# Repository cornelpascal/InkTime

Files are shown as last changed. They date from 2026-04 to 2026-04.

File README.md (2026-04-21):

# InkTime

- Cerinta proiectului: https://ocw.cs.pub.ro/courses/tsc/proiect2026
- Portalul de piese JLC mentionat in brief: https://jlcpcb.com/parts

Repository-ul contine schema electrica, PCB-ul, fisierele de manufacturing si ansamblul mecanic pentru un wearable bazat pe nRF52840, cu Bluetooth Low Energy, incarcare prin USB-C, interfata pentru display e-paper, motion sensing, haptic feedback si monitorizare baterie.

## Continutul Repository-ului

- `Hardware/`
  - `WatchSchematic.sch` - schema nativa
  - `WatchSchematic.brd` - layout PCB nativ
  - `WatchSchematic.pdf` / `WatchSchematic1.pdf` - exporturi PDF ale schemei
- `Manufacturing/`
  - `Gerbers.zip` - exporturi Gerber, drill si assembly
  - `bom.csv` - export BOM pentru manufacturing
  - `pick_and_place_top.cpl` - date de plasare pentru fata top
  - `pick_and_place_bottom.cpl` - date de plasare pentru fata bottom
- `Mechanical/`
  - `WatchMechanical.f3z` - assembly Fusion 360
  - `WatchMechanical.step` - export CAD neutru
- `Images/`
  - capturi de render pentru PCB/dispozitiv

## Diagrama Bloc

```text
                         +----------------------+
USB-C -----------------> | USB ESD Protection   |
                         +----------+-----------+
                                    |
                                    v
                         +----------------------+
                         | BQ25180 Charger/PMIC |
                         +----+------------+----+
                              |            |
                              |            +--------------------+
                              v                                 |
                       +-------------+                          |
                       | Li-Po       |                          |
                       | Battery     | --------------------+   |
                       +------+------+                     |   |
                              |                            v   v
                              |                  +----------------------+
                              +----------------> | MAX17048 Fuel Gauge  |
                                                 +----------------------+

                         +----------------------+
                         | RT6160A Buck-Boost   |
                         | 3.3 V Regulator      |
                         +----+----+----+-------+
                              |    |    |
                              |    |    +---------------------> Display E-Paper pe FPC 24 pini
                              |    |
                              |    +-------------------------> DRV2605 Haptic Driver ---> Motor vibratii
                              |
                              +------------------------------> BMA423 IMU
                              |
                              v
                    +-----------------------------------+
                    | nRF52840 BLE + USB MCU            |
                    |                                   |
                    | I2C  -> PMIC / Fuel / IMU / Haptic|
                    | SPI  -> Display E-Paper           |
                    | GPIO -> Butoane / INT / EN        |
                    | USB  -> D+ / D-                   |
                    | SWD  -> Debug Tag-Connect         |
                    +-----+-----------+--------+--------+
                          |           |        |
                          |           |        +--------> Tag-Connect SWD
                          |           +-----------------> 3 butoane user
                          +-----------------------------> Matching Network -> Antena 2.4 GHz
```

## Prezentare Hardware

### Arhitectura principala

- `nRF52840` este controlerul principal. A fost ales deoarece combina BLE, USB, suficienti GPIO, moduri low-power si un ecosistem RF intr-un singur pachet.
- Alimentarea intra prin `USB-C`, trece prin protectia ESD si este gestionata de `BQ25180YBGR`, un charger / PMIC pentru o singura celula.
- Linia de alimentare sustinuta de baterie este reglata de `RT6160AWSC`, un convertor buck-boost care genereaza rail-ul principal `3V3` indiferent de variatia tensiunii bateriei.
- Starea bateriei este masurata de `MAX17048G+T10`.
- Motion sensing este oferit de `BMA423`.
- Haptic feedback este generat de `DRV2605YZFR`, controlat prin I2C si activat printr-un GPIO dedicat.
- Display-ul este conectat printr-un conector `FPC 24 pini, 0.5 mm` si foloseste o magistrala dedicata de tip SPI plus linii de reset/busy/control.
- Semnalul RF de la nRF52840 trece printr-o retea discreta de matching catre o antena chip de 2.4 GHz plasata pe marginea PCB-ului.

### Decizii de design vizibile in implementare

- Toate componentele populate sunt plasate pe fata top; fisierul pick-and-place pentru bottom este gol, conform ghidajului din cerinta.
- Antena RF este pastrata pe marginea placii si separata de zonele dense de cupru, ceea ce respecta cerinta proiectului privind clearance-ul antenei.
- Ceasul foloseste trei butoane hardware pe GPIO-uri dedicate in loc sa le multiplexeze prin display sau PMIC.

## Bill of Materials

BOM-ul complet exportat pentru manufacturing este in [`Manufacturing/bom.csv`](Manufacturing/bom.csv). Tabelul de mai jos listeaza componentele functionale principale, iar coloana `JLC Parts` foloseste fie linkul exact extras din proiect, fie portalul JLC Parts pentru cautarea manuala dupa MPN atunci cand codul JLC nu apare explicit in export.

| Ref | Part | Rol | JLC Parts | Datasheet |
| --- | --- | --- | --- | --- |
| `U1` | nRF52840 | MCU principal BLE/USB | https://jlcpcb.com/partdetail/JLCPCBAssembly-nRF52840/C9900031370 | https://www.nordicsemi.com/-/media/Software-and-other-downloads/Product-Briefs/nRF52840-product-brief.pdf |
| `IC1` | BQ25180YBGR | Charger / PMIC pentru o singura celula | https://jlcpcb.com/partdetail/TexasInstruments-BQ25180YBGR/C3682423 | https://www.ti.com/lit/ds/symlink/bq25180.pdf |
| `IC9` | RT6160AWSC | Regulator buck-boost 3.3 V | https://jlcpcb.com/partdetail/C7065276 | https://www.richtek.com/assets/product_file/RT6160A=RTQ2520A/DS6160A-05.pdf |
| `U3` | MAX17048G+T10 | Fuel gauge pentru baterie | https://jlcpcb.com/partdetail/MaximIntegrated-MAX17048GT10/C2682616 | https://www.analog.com/media/en/technical-documentation/data-sheets/MAX17048-MAX17049.pdf |
| `IC2` | DRV2605YZFR | Driver haptic | https://jlcpcb.com/partdetail/TexasInstruments-DRV2605YZFR/C81079 | https://www.ti.com/lit/ds/symlink/drv2605.pdf |
| `L7` | FTC252012SR47MBCA | Inductor pentru buck-boost | https://jlcpcb.com/partdetail/6763488-FTC252012SR47MBCA/C5832368 | https://product.tdk.com/system/files/dam/doc/product/inductor/inductor/smd/catalog/inductor_commercial_power_mlp2016_en.pdf |
| `IC3` | BMA423 | Accelerometru pe 3 axe | https://jlcpcb.com/parts | https://www.bosch-sensortec.com/media/boschsensortec/downloads/datasheets/bst-bma423-ds000.pdf |
| `ANT1` | 2450AT18B100E | Antena chip 2.4 GHz | https://jlcpcb.com/parts | https://www.johansontechnology.com/datasheets/2450AT18B100.pdf |
| `J1` | Molex 503480-2400 | Conector FPC 24 pini pentru display | https://jlcpcb.com/parts | https://www.molex.com/pdm_docs/sd/5034802400_sd.pdf |
| `J2` | TC2030-IDC | Conector de programare Tag-Connect | https://jlcpcb.com/parts | https://www.tag-connect.com/wp-content/uploads/bsk-pdf-manager/TC2030-IDC-NL.pdf |
| `J4` | KH-TYPE-C-16P | Receptacul USB-C | https://jlcpcb.com/parts | https://atta.szlcsc.com/upload/public/pdf/source/20230720/8A9E0F0B650D1A2FD53D4D542E2F6B37.pdf |
| `D3` | USBLC6-2SC6Y | Protectie ESD pentru USB | https://jlcpcb.com/parts | https://www.st.com/resource/en/datasheet/usblc6-2.pdf |
| `SW_UP`, `SW_ENT`, `SW_DN` | Panasonic EVP-AKE31A | Butoane user | https://jlcpcb.com/parts | https://industry.panasonic.com/cdbs/www-data/pdf/ASQ0000/ASQ0000CE50.pdf |

## Alocare Pini nRF52840

Tabelul urmator documenteaza alocarile efective observate in schema pentru `U1` (`nRF52840`).

| Pin nRF52840 | Net / semnal | Utilizare in design |
| --- | --- | --- |
| `P0.00` | `XL1` | Terminal cristal LF 32.768 kHz |
| `P0.01` | `XL2` | Terminal cristal LF 32.768 kHz |
| `P0.02` | `SCK` | SPI clock pentru display-ul e-paper |
| `P0.03` | `MOSI` | SPI MOSI pentru display-ul e-paper |
| `P0.05` | `EPD_CS` | Chip select pentru display |
| `P0.06` | `SDA` | I2C SDA comun pentru PMIC, fuel gauge, haptic si alte periferice I2C |
| `P0.07` | `SCL` | I2C SCL comun pentru PMIC, fuel gauge, haptic si alte periferice I2C |
| `P0.08` | `IMU_INT1` | Intrerupere principala de la `BMA423` |
| `P0.10` | `ALERT` | Semnal `ALERT` de la `MAX17048` |
| `P0.11` | `PMIC_INT` | Intrerupere de la `BQ25180` |
| `P0.12` | `HAPTIC_EN` | Enable pentru `DRV2605` |
| `P0.13` | `P0.13` | Intrare buton `SW_UP` |
| `P0.14` | `P0.14` | Intrare buton `SW_ENT` |
| `P0.15` | `EPD_DC` | Linia data/command pentru display |
| `P0.16` | `EPD_RST` | Reset hardware pentru display |
| `P0.17` | `EPD_BUSY` | Busy/status de la display |
| `P0.18` | `RESET` | Reset extern, dus si la Tag-Connect (`J2`) |
| `P1.00` | `SWO` | Optional trace / debug output pe test pad |
| `P1.02` | `P1.02` | Intrare buton `SW_DN` |
| `P1.08` | `IMU_INT2` | A doua intrerupere de la `BMA423` |
| `SWDIO` | `SWDIO` | Debug/programare prin `J2` |
| `SWDCLK` | `SWDCLK` | Clock debug/programare prin `J2` |
| `D-` | `D-` | USB FS data minus de la conectorul USB-C, prin protectia ESD |
| `D+` | `D+` | USB FS data plus de la conectorul USB-C, prin protectia ESD |
| `VBUS` | `VBUS` | Detectie/alimentare USB venita din conectorul USB-C |

Pinii `P0.04`, `P0.09`, `P1.01`, `P1.03`-`P1.07`, `P1.09`-`P1.15` si `P0.19`-`P0.31` apar in simbolul MCU, dar in schema curenta nu au o functie periferica documentata explicit; pot ramane disponibili pentru extensii sau pentru iteratii viitoare ale designului.

## Fisiere de Manufacturing

Artefactele prezente in acest repository:

- Arhiva Gerber: [`Manufacturing/Gerbers.zip`](Manufacturing/Gerbers.zip)
- Datele de drill incluse in arhiva
- Fisiere de assembly placement:
  - [`Manufacturing/pick_and_place_top.cpl`](Manufacturing/pick_and_place_top.cpl)
  - [`Manufacturing/pick_and_place_bottom.cpl`](Manufacturing/pick_and_place_bottom.cpl)
- Export BOM: [`Manufacturing/bom.csv`](Manufacturing/bom.csv)

Arhiva Gerber curenta contine fisiere pentru top/bottom copper, soldermask, silkscreen, solderpaste, drill si profile. Fisierul de plasare pentru top este populat; fisierul de plasare pentru bottom este gol, ceea ce este consistent cu o strategie de asamblare doar pe fata top.

## Livrabile Mecanice

- Ansamblu Fusion: [`Mechanical/WatchMechanical.f3z`](Mechanical/WatchMechanical.f3z)
- Export STEP: [`Mechanical/WatchMechanical.step`](Mechanical/WatchMechanical.step)

Aceste fisiere sunt destinate validarii potrivirii carcasei pentru PCB, baterie, stack-ul display-ului si alinierea conectorilor/butoanelor ceruta de proiect.

## Imagini Render

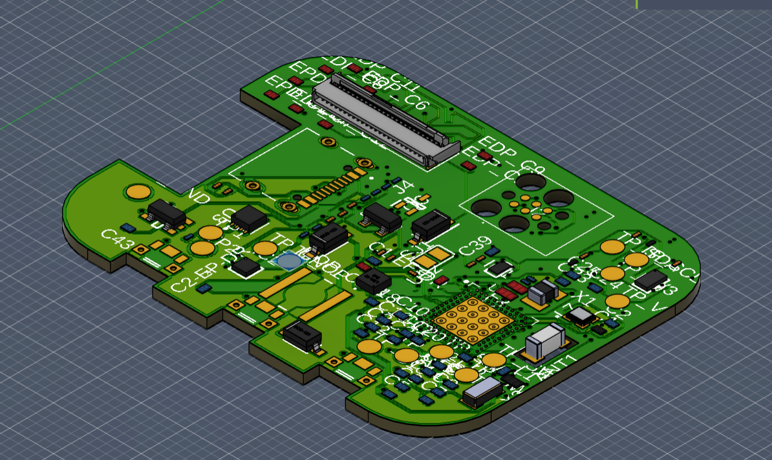
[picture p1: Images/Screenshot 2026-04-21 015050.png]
Render 1

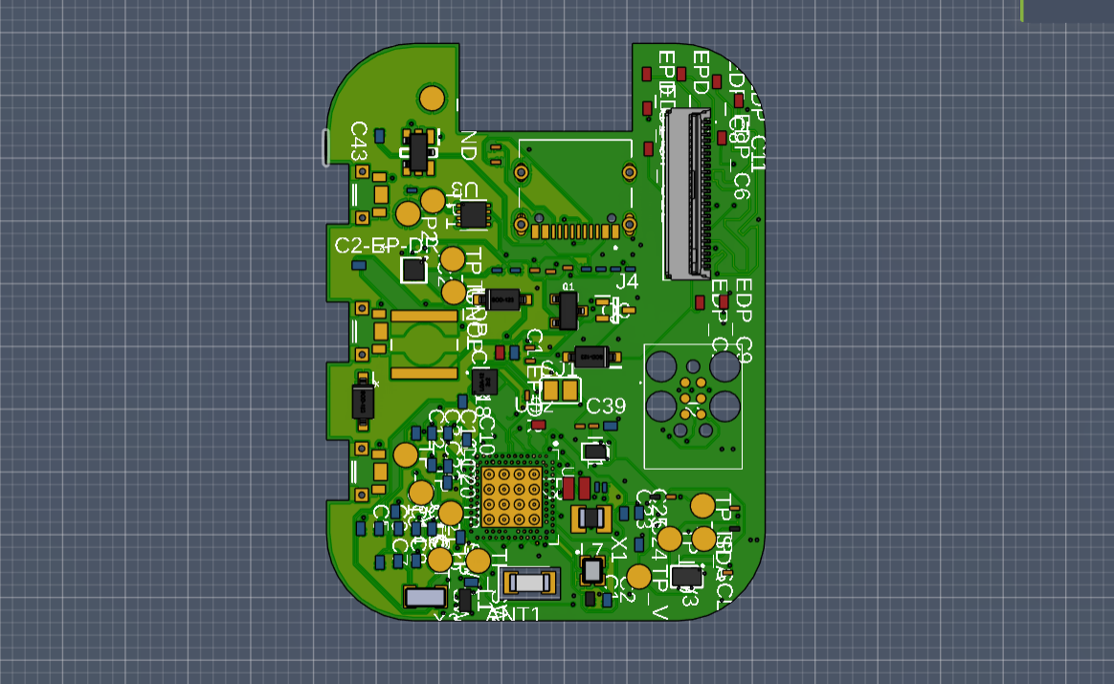
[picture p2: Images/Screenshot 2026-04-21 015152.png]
Render 2

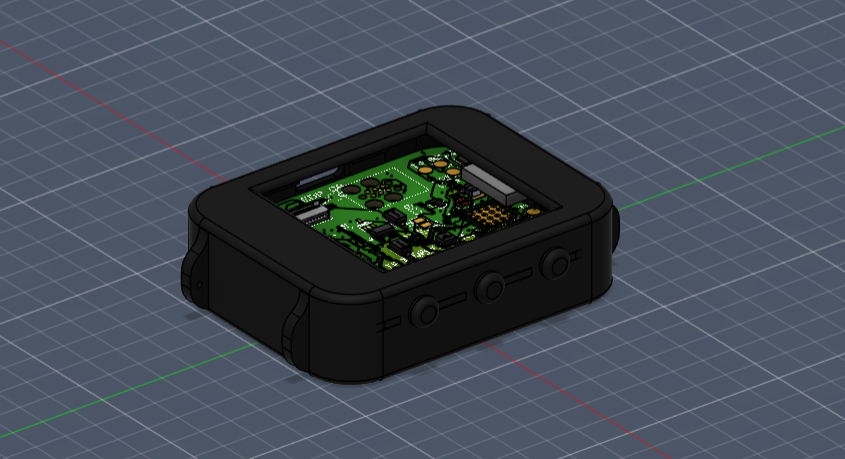
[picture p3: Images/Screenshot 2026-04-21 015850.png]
Render 3

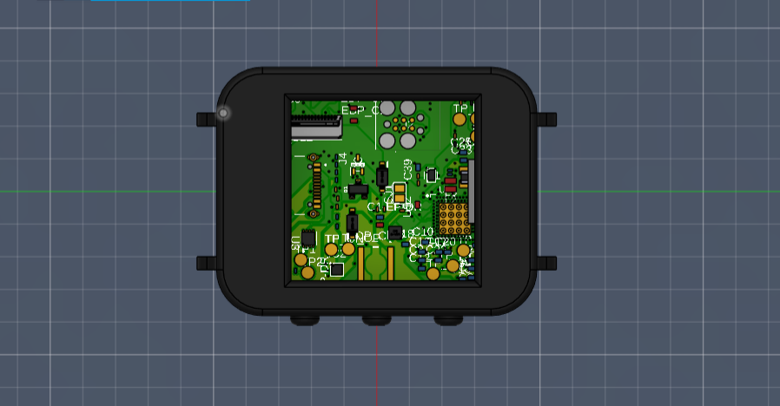
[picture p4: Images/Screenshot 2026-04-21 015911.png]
Render 4


## Note de Implementare

- Designul urmeaza structura ceruta de proiect pentru `Hardware`, `Manufacturing`, `Mechanical`, `Images`, `LICENSE` si `README.md`.
- PCB-ul este o placa compacta pentru wearable, cu functii RF, power, sensing, haptics, display, USB si debug integrate intr-un singur design.
- Arhitectura aleasa minimizeaza modulele externe prin integrarea directa pe placa a functiilor de charging, regulation, sensing, battery monitoring si control haptic.
- Zonele cele mai sensibile la rutare sunt traseul RF, regiunea perechii diferentiale USB, zona de conversie de putere si sectiunea densa a conectorului de display.

## Aliniere cu Checklist-ul de Review

Acest README a fost scris pentru a acoperi documentatia necesara:

- diagrama bloc
- BOM cu linkuri de procurement si datasheet
- functionalitate hardware detaliata
- utilizarea explicita a pinilor nRF52840
- note de implementare utile in timpul review-ului
- linkuri catre schema, PCB-ul, fisierele de manufacturing si artefactele mecanice livrate

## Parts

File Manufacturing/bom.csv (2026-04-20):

Part | Value | Device | Footprint Name | Detailed Description | ARROW_PART_NUMBER | ARROW_PRICE-STOCK | AVAILABILITY | CHECK_PRICES | COPYRIGHT | DESCRIPTION | DIGI-KEY_PART_NUMBER_1 | DIGI-KEY_PART_NUMBER_2 | DIGI-KEY_PART_NUMBER_3 | HEIGHT | JLCPCB | MANUFACTURER_NAME | MANUFACTURER_PART_NUMBER | MF | MFR_NAME | MOUSER_PART_NUMBER | MOUSER_PRICE-STOCK | MP | PACKAGE | POPULARITY | PRICE | PROD_ID | PURCHASE-URL | SNAPEDA_LINK | TP_SIGNAL_NAME | VALUE
ANT1 | 2450AT18B100E_2450AT18B100E | 2450AT18B100E_2450AT18B100E | 2450AT18B100E_ANTC3216X140N | Antennas 2.45GHz ANTENNA | 2450AT18B100E | https://www.arrow.com/en/products/2450at18b100e/johanson-dielectrics?utm_currency=USD&region=nac |  |  |  | Antennas 2.45GHz ANTENNA |  |  |  | 1.4mm |  | JOHANSON TECHNOLOGY | 2450AT18B100E |  |  | 609-2450AT18B100E | https://www.mouser.co.uk/ProductDetail/Johanson-Technology/2450AT18B100E?qs=yCnrNFeXz%252Bh5MFsFIXGZGA%3D%3D
C1 | 12pF | NORDIC_NRF_3_CAPACITOR_0201_L | NORDIC_NRF_3_RESC0201_L | Generic chip capacitor
C1-EP-DR | 10uF | NORDIC_NRF_3_CAPACITOR_0201_L | NORDIC_NRF_3_RESC0201_L | Generic chip capacitor
C2 | 12pF | NORDIC_NRF_3_CAPACITOR_0201_L | NORDIC_NRF_3_RESC0201_L | Generic chip capacitor
C2-EP-DR | 4.7uF/25V | NORDIC_NRF_3_CAPACITOR_0201_L | NORDIC_NRF_3_RESC0201_L | Generic chip capacitor
C3 | 1pF | NORDIC_NRF_3_CAPACITOR_0201_L | NORDIC_NRF_3_RESC0201_L | Generic chip capacitor
C4 | 1pF | NORDIC_NRF_3_CAPACITOR_0201_L | NORDIC_NRF_3_RESC0201_L | Generic chip capacitor
C5 | 100nF | NORDIC_NRF_3_CAPACITOR_0201_L | NORDIC_NRF_3_RESC0201_L | Generic chip capacitor
C6 | 4.7µF | NORDIC_NRF_3_CAPACITOR_0201_L | NORDIC_NRF_3_RESC0201_L | Generic chip capacitor
C7 | 100nF | NORDIC_NRF_3_CAPACITOR_0201_L | NORDIC_NRF_3_RESC0201_L | Generic chip capacitor
C8 | 100nF | NORDIC_NRF_3_CAPACITOR_0201_L | NORDIC_NRF_3_RESC0201_L | Generic chip capacitor
C9 | 820pF | NORDIC_NRF_3_CAPACITOR_0201_L | NORDIC_NRF_3_RESC0201_L | Generic chip capacitor
C10 | N.C. | NORDIC_NRF_3_CAPACITOR_0201_L | NORDIC_NRF_3_RESC0201_L | Generic chip capacitor
C11 | 100pF | NORDIC_NRF_3_CAPACITOR_0201_L | NORDIC_NRF_3_RESC0201_L | Generic chip capacitor
C12 | 100nF | NORDIC_NRF_3_CAPACITOR_0201_L | NORDIC_NRF_3_RESC0201_L | Generic chip capacitor
C13 | N.C. | NORDIC_NRF_3_CAPACITOR_0201_L | NORDIC_NRF_3_RESC0201_L | Generic chip capacitor
C14 | 4.7µF | NORDIC_NRF_3_CAPACITOR_0201_L | NORDIC_NRF_3_RESC0201_L | Generic chip capacitor
C15 | 1.0µF | NORDIC_NRF_3_CAPACITOR_0201_L | NORDIC_NRF_3_RESC0201_L | Generic chip capacitor
C16 | 47nF | NORDIC_NRF_3_CAPACITOR_0201_L | NORDIC_NRF_3_RESC0201_L | Generic chip capacitor
C17 | 12pF | NORDIC_NRF_3_CAPACITOR_0201_L | NORDIC_NRF_3_RESC0201_L | Generic chip capacitor
C18 | 12pF | NORDIC_NRF_3_CAPACITOR_0201_L | NORDIC_NRF_3_RESC0201_L | Generic chip capacitor
C20 | 4.7µF | NORDIC_NRF_3_CAPACITOR_0201_L | NORDIC_NRF_3_RESC0201_L | Generic chip capacitor
C21 | 4.7µF | NORDIC_NRF_3_CAPACITOR_0201_L | NORDIC_NRF_3_RESC0201_L | Generic chip capacitor
C22 | N.C. | NORDIC_NRF_3_CAPACITOR_0201_L | NORDIC_NRF_3_RESC0201_L | Generic chip capacitor
C23 | 0.1uF | GRM011R60J152KE01L_1_GRM011R60J152KE01L | GRM011R60J152KE01L_1_0201 | Check availability
C24 | 10uF | NORDIC_NRF_3_CAPACITOR_0201_L | NORDIC_NRF_3_RESC0201_L | Generic chip capacitor
C25 | 22uF | NORDIC_NRF_3_CAPACITOR_0201_L | NORDIC_NRF_3_RESC0201_L | Generic chip capacitor
C27 | 0.1uF | GRM011R60J152KE01L_1_GRM011R60J152KE01L | GRM011R60J152KE01L_1_0201 | Check availability
C29 | 1uF | GRM011R60J152KE01L_1_GRM011R60J152KE01L | GRM011R60J152KE01L_1_0201 | Check availability
C30 | 1uF | GRM011R60J152KE01L_1_GRM011R60J152KE01L | GRM011R60J152KE01L_1_0201 | Check availability
C31 | 1uF | GRM011R60J152KE01L_1_GRM011R60J152KE01L | GRM011R60J152KE01L_1_0201 | Check availability
C32 | 1uF | GRM011R60J152KE01L_1_GRM011R60J152KE01L | GRM011R60J152KE01L_1_0201 | Check availability
C33 | 22uF | NORDIC_NRF_3_CAPACITOR_0201_L | NORDIC_NRF_3_RESC0201_L | Generic chip capacitor
C34 | 0.1uF | GRM011R60J152KE01L_1_GRM011R60J152KE01L | GRM011R60J152KE01L_1_0201 | Check availability
C37 | 1uF | GRM011R60J152KE01L_1_GRM011R60J152KE01L | GRM011R60J152KE01L_1_0201 | Check availability
C38 | 1uF | GRM011R60J152KE01L_1_GRM011R60J152KE01L | GRM011R60J152KE01L_1_0201 | Check availability
C39 | 10uF | NORDIC_NRF_3_CAPACITOR_0201_L | NORDIC_NRF_3_RESC0201_L | Generic chip capacitor
C42 | 0.1uF | GRM011R60J152KE01L_1_GRM011R60J152KE01L | GRM011R60J152KE01L_1_0201 | Check availability
C43 | 4.7uF | NORDIC_NRF_3_CAPACITOR_0201_L | NORDIC_NRF_3_RESC0201_L | Generic chip capacitor
D2 | ESP32_C6_LIBRARY_5_MBR0530 | ESP32_C6_LIBRARY_5_MBR0530 | ESP32_C6_LIBRARY_5_SOD3716X135N | ON SEMICONDUCTOR - MBR0530 - DIODE, SCHOTTKY, 0.5A, 30V, SOD-123 |  |  | In Stock | https://www.snapeda.com/parts/MBR0530/Onsemi/view-part/?ref=eda |  | Diode Schottky 30 V 500mA Surface Mount SOD-123 |  |  |  |  |  |  |  | ON Semiconductor |  |  |  | MBR0530 | SOD-123-2 ON Semiconductor |  | None |  | https://www.snapeda.com/api/url_track_click_mouser/?unipart_id=179458&manufacturer=ON Semiconductor&part_name=MBR0530&search_term=None | https://www.snapeda.com/parts/MBR0530/Onsemi/view-part/?ref=snap
D3 | ESP32_C6_LIBRARY_3_USBLC6-2SC6Y | ESP32_C6_LIBRARY_3_USBLC6-2SC6Y | ESP32_C6_LIBRARY_3_SOT95P280X145-6N | Low Cap. ESD Protection Auto SOT-23-6 STMicroelectronics USBLC6-2SC6Y, Dual Uni-Directional TVS Diode Array, 6-Pin SOT-23 |  |  | In Stock | https://www.snapeda.com/parts/USBLC6-2SC6Y/STMicroelectronics/view-part/?ref=eda |  | 17V Clamp 5A (8/20µs) Ipp Tvs Diode Surface Mount SOT-23-6 |  |  |  |  |  |  |  | STMicroelectronics |  |  |  | USBLC6-2SC6Y | SOT-23-6 STMicroelectronics |  | None |  |  | https://www.snapeda.com/parts/USBLC6-2SC6Y/STMicroelectronics/view-part/?ref=snap
D4 | ESP32_C6_LIBRARY_5_MBR0530 | ESP32_C6_LIBRARY_5_MBR0530 | ESP32_C6_LIBRARY_5_SOD3716X135N | ON SEMICONDUCTOR - MBR0530 - DIODE, SCHOTTKY, 0.5A, 30V, SOD-123 |  |  | In Stock | https://www.snapeda.com/parts/MBR0530/Onsemi/view-part/?ref=eda |  | Diode Schottky 30 V 500mA Surface Mount SOD-123 |  |  |  |  |  |  |  | ON Semiconductor |  |  |  | MBR0530 | SOD-123-2 ON Semiconductor |  | None |  | https://www.snapeda.com/api/url_track_click_mouser/?unipart_id=179458&manufacturer=ON Semiconductor&part_name=MBR0530&search_term=None | https://www.snapeda.com/parts/MBR0530/Onsemi/view-part/?ref=snap
D5 | ESP32_C6_LIBRARY_5_MBR0530 | ESP32_C6_LIBRARY_5_MBR0530 | ESP32_C6_LIBRARY_5_SOD3716X135N | ON SEMICONDUCTOR - MBR0530 - DIODE, SCHOTTKY, 0.5A, 30V, SOD-123 |  |  | In Stock | https://www.snapeda.com/parts/MBR0530/Onsemi/view-part/?ref=eda |  | Diode Schottky 30 V 500mA Surface Mount SOD-123 |  |  |  |  |  |  |  | ON Semiconductor |  |  |  | MBR0530 | SOD-123-2 ON Semiconductor |  | None |  | https://www.snapeda.com/api/url_track_click_mouser/?unipart_id=179458&manufacturer=ON Semiconductor&part_name=MBR0530&search_term=None | https://www.snapeda.com/parts/MBR0530/Onsemi/view-part/?ref=snap
EDP_C5 | 0.1uF/50V | NORDIC_NRF_3_CAPACITOR_0201_L | NORDIC_NRF_3_RESC0201_L | Generic chip capacitor
EDP_C6 | 1uF/50V | NORDIC_NRF_3_CAPACITOR_0201_L | NORDIC_NRF_3_RESC0201_L | Generic chip capacitor
EDP_C7 | 1uF/50V | NORDIC_NRF_3_CAPACITOR_0201_L | NORDIC_NRF_3_RESC0201_L | Generic chip capacitor
EDP_C8 | 1uF/50V | NORDIC_NRF_3_CAPACITOR_0201_L | NORDIC_NRF_3_RESC0201_L | Generic chip capacitor
EDP_C9 | 1uF/50V | NORDIC_NRF_3_CAPACITOR_0201_L | NORDIC_NRF_3_RESC0201_L | Generic chip capacitor
EDP_C10 | 1uF/50V | NORDIC_NRF_3_CAPACITOR_0201_L | NORDIC_NRF_3_RESC0201_L | Generic chip capacitor
EDP_C11 | 1uF/50V | NORDIC_NRF_3_CAPACITOR_0201_L | NORDIC_NRF_3_RESC0201_L | Generic chip capacitor
EDP_C12 | 1uF/50V | NORDIC_NRF_3_CAPACITOR_0201_L | NORDIC_NRF_3_RESC0201_L | Generic chip capacitor
EPD_C1 | 1uF/50V | NORDIC_NRF_3_CAPACITOR_0201_L | NORDIC_NRF_3_RESC0201_L | Generic chip capacitor
EPD_C2 | 1uF/50V | NORDIC_NRF_3_CAPACITOR_0201_L | NORDIC_NRF_3_RESC0201_L | Generic chip capacitor
IC1 | BQ25180YBGR_BQ25180YBGR | BQ25180YBGR_BQ25180YBGR | BQ25180YBGR_BGA8C40P2X4_100X155X50 | Charger IC Lithium Ion/Polymer, Lithium Iron Phosphate 8-DSBGA (1.6x1.1) | BQ25180YBGR | https://www.arrow.com/en/products/bq25180ybgr/texas-instruments?utm_currency=USD&region=nac |  |  |  | Charger IC Lithium Ion/Polymer, Lithium Iron Phosphate 8-DSBGA (1.6x1.1) |  |  |  | 0.5mm |  | Texas Instruments | BQ25180YBGR |  |  | 595-BQ25180YBGR | https://www.mouser.co.uk/ProductDetail/Texas-Instruments/BQ25180YBGR?qs=doiCPypUmgEWjAK%252BJAX6Tw%3D%3D
IC2 | DRV2605YZFR_DRV2605YZFR | DRV2605YZFR_DRV2605YZFR | DRV2605YZFR_BGA9C50P3X3_144X144X62 | Haptic Driver for ERM/LRA with Built-In Library and Smart Loop Architecture | DRV2605YZFR | https://www.arrow.com/en/products/drv2605yzfr/texas-instruments?region=nac |  |  |  | Haptic Driver for ERM/LRA with Built-In Library and Smart Loop Architecture |  |  |  | 0.625mm |  | Texas Instruments | DRV2605YZFR
IC3 | BMA423_BMA423 | BMA423_BMA423 | BMA423_BMA423 | Accelerometers Triaxial low-g 12bit Acceleration Sensor | BMA423 | https://www.arrow.com/en/products/bma423/bosch |  |  |  | Accelerometers Triaxial low-g 12bit Acceleration Sensor |  |  |  | 1mm |  | BOSCH | BMA423 |  |  | 262-BMA423 | https://www.mouser.co.uk/ProductDetail/Bosch-Sensortec/BMA423?qs=HXFqYaX1Q2xC%252BSgeGoX3mg%3D%3D
IC9 | RT6160AWSC_RT6160AWSC | RT6160AWSC_RT6160AWSC | RT6160AWSC_BGA15C40P3X5_140X230X60 | Buck-Boost Regulator Positive Output Step-Up/Step-Down I2C DC-DC Controller IC 15-WL-CSP (BSC) (1.4x2.3) |  |  |  |  |  | Buck-Boost Regulator Positive Output Step-Up/Step-Down I2C DC-DC Controller IC 15-WL-CSP (BSC) (1.4x2.3) |  |  |  | 0.6mm |  | RICHTEK | RT6160AWSC |  |  | 835-RT6160AWSC | https://www.mouser.co.uk/ProductDetail/Richtek/RT6160AWSC?qs=amGC7iS6iy%2FLd9PSoixZXQ%3D%3D
J1 | 503480-2400_503480-2400 | 503480-2400_503480-2400 | 503480-2400_5034802400 | FFC & FPC Connectors 0.5mm FPC RA SMT Dual Contact 24Ckt |  |  |  |  |  | FFC & FPC Connectors 0.5mm FPC RA SMT Dual Contact 24Ckt |  |  |  | 1.87mm |  | Molex | 503480-2400 |  |  | 538-503480-2400 | https://www.mouser.co.uk/ProductDetail/Molex/503480-2400?qs=OAhjpuo3Vu7efIoxFh9AOw%3D%3D
J2 | TC2030-IDC_TC2030-IDC | TC2030-IDC_TC2030-IDC | TC2030-IDC_TC2030IDC | CABLE ADAPTER 6 POS |  |  |  |  |  | CABLE ADAPTER 6 POS |  |  |  | 19mm |  | Tag Connect | TC2030-IDC
J4 | KH-TYPE-C-16P_KH-TYPE-C-16P | KH-TYPE-C-16P_KH-TYPE-C-16P | KH-TYPE-C-16P_KINGHELM_KH-TYPE-C-16P | Check availability |  |  | Not in stock | https://www.snapeda.com/parts/KH-TYPE-C-16P/Kinghelm/view-part/?ref=eda |  |  |  |  |  |  |  |  |  | kinghelm |  |  |  | KH-TYPE-C-16P | None |  | None |  |  | https://www.snapeda.com/parts/KH-TYPE-C-16P/Kinghelm/view-part/?ref=snap
L1 | 3.9nH | NORDIC_NRF_2_INDUCTOR_0402_L | NORDIC_NRF_2_RESC0402_L | Generic chip inductor
L2 | 10µH | NORDIC_NRF_2_INDUCTOR_0402_L | NORDIC_NRF_2_RESC0402_L | Generic chip inductor
L3 | 15nH | NORDIC_NRF_2_INDUCTOR_0402_L | NORDIC_NRF_2_RESC0402_L | Generic chip inductor
L5 | 68uH | ESP32_C6_LIBRARY_2_744043680IND_4828-WE-TPC_WRE | ESP32_C6_LIBRARY_2_IND_4828-WE-TPC_WRE |  |  |  |  |  | Copyright (C) 2024 Ultra Librarian. All rights reserved. |  |  |  |  |  |  |  | 744043680 |  | Wurth Electronics
L7 | MLP2016SR47MT0S1_FTC252012SR47MBCA | MLP2016SR47MT0S1_FTC252012SR47MBCA | MLP2016SR47MT0S1_INDC2016X100N | SMD / SMT Inductors (Coils), L=0.47?H, L x W x T : |  |  |  |  |  | SMD / SMT Inductors (Coils), L=0.47?H, L x W x T : |  |  |  | 1mm | https://jlcpcb.com/partdetail/6763488-FTC252012SR47MBCA/C5832368 | TDK | FTC252012SR47MBCA
Q1 | 20V/4.2A/52mO/1.4W | ESP32_C6_LIBRARY_4_ESP32_WROVER_SPARKFUN-DISCRETESEMI_MOSFET_PCH-DMG2305UX-7 | ESP32_C6_LIBRARY_4_ESP32_C6_LIBRARY_4_ESP32_C6_LIBRARY_4_ESP32_C6_LIBRARY_4_ESP32_WROVER_SPARKFUN-DISCRETESEMI_SOT23-3 | P-channel MOSFETs |  |  |  |  |  |  |  |  |  |  |  |  |  |  |  |  |  |  |  |  |  | TRAN-14388 |  |  |  | 20V/4.2A/52mO/1.4W
Q3 | ESP32_C6_LIBRARY_6_SI1308EDL-T1-GE3 | ESP32_C6_LIBRARY_6_SI1308EDL-T1-GE3 | ESP32_C6_LIBRARY_6_SOT65P210X110-3N | MOSFET N-Ch 30V 1.5A TrenchFET SC70 Vishay Si1308EDL-T1-GE3 N-channel MOSFET Transistor, 1.5 A, 30 V, 3-Pin SC-70 |  |  | In Stock | https://www.snapeda.com/parts/SI1308EDL-T1-GE3/Vishay+Siliconix/view-part/?ref=eda |  | Si1308EDL-T1-GE3 N-channel MOSFET Transistor, 1.5 A, 30 V, 3-Pin SC-70 | Siliconix / Vishay SI1308EDL-T1-GE3 |  |  |  |  |  |  |  | Vishay Siliconix |  |  |  | SI1308EDL-T1-GE3 | SOT-323 Vishay Semiconductor |  | None |  | https://www.snapeda.com/api/url_track_click_mouser/?unipart_id=274603&manufacturer=Vishay Siliconix&part_name=SI1308EDL-T1-GE3&search_term=None | https://www.snapeda.com/parts/SI1308EDL-T1-GE3/Vishay+Siliconix/view-part/?ref=snap
R1_EP_DR | 0.47 | CPF0201D7K68C1_CPF0201D7K68C1 | CPF0201D7K68C1_0201 | 7.68k 0201 Thin Film Surface Mount Fixed Resistor +/-0.5% 0.031W CPF0201D7K68C1
R1_USB | 5K1 | CPF0201D7K68C1_CPF0201D7K68C1 | CPF0201D7K68C1_0201 | 7.68k 0201 Thin Film Surface Mount Fixed Resistor +/-0.5% 0.031W CPF0201D7K68C1
R2 | 0 | CPF0201D7K68C1_CPF0201D7K68C1 | CPF0201D7K68C1_0201 | 7.68k 0201 Thin Film Surface Mount Fixed Resistor +/-0.5% 0.031W CPF0201D7K68C1
R2_EP_DR | 10K | CPF0201D7K68C1_CPF0201D7K68C1 | CPF0201D7K68C1_0201 | 7.68k 0201 Thin Film Surface Mount Fixed Resistor +/-0.5% 0.031W CPF0201D7K68C1
R2_USB | 5K1 | CPF0201D7K68C1_CPF0201D7K68C1 | CPF0201D7K68C1_0201 | 7.68k 0201 Thin Film Surface Mount Fixed Resistor +/-0.5% 0.031W CPF0201D7K68C1
R3 | 0 | CPF0201D7K68C1_CPF0201D7K68C1 | CPF0201D7K68C1_0201 | 7.68k 0201 Thin Film Surface Mount Fixed Resistor +/-0.5% 0.031W CPF0201D7K68C1
R4 | 0 | CPF0201D7K68C1_CPF0201D7K68C1 | CPF0201D7K68C1_0201 | 7.68k 0201 Thin Film Surface Mount Fixed Resistor +/-0.5% 0.031W CPF0201D7K68C1
R5 | 10k | CPF0201D7K68C1_CPF0201D7K68C1 | CPF0201D7K68C1_0201 | 7.68k 0201 Thin Film Surface Mount Fixed Resistor +/-0.5% 0.031W CPF0201D7K68C1
R7 | 10k | CPF0201D7K68C1_CPF0201D7K68C1 | CPF0201D7K68C1_0201 | 7.68k 0201 Thin Film Surface Mount Fixed Resistor +/-0.5% 0.031W CPF0201D7K68C1
R8 | 10k | CPF0201D7K68C1_CPF0201D7K68C1 | CPF0201D7K68C1_0201 | 7.68k 0201 Thin Film Surface Mount Fixed Resistor +/-0.5% 0.031W CPF0201D7K68C1
R9 | 10K | CPF0201D7K68C1_CPF0201D7K68C1 | CPF0201D7K68C1_0201 | 7.68k 0201 Thin Film Surface Mount Fixed Resistor +/-0.5% 0.031W CPF0201D7K68C1
R17 | 3K3 | CPF0201D7K68C1_CPF0201D7K68C1 | CPF0201D7K68C1_0201 | 7.68k 0201 Thin Film Surface Mount Fixed Resistor +/-0.5% 0.031W CPF0201D7K68C1
R18 | 3K3 | CPF0201D7K68C1_CPF0201D7K68C1 | CPF0201D7K68C1_0201 | 7.68k 0201 Thin Film Surface Mount Fixed Resistor +/-0.5% 0.031W CPF0201D7K68C1
R_PWR_EDP | 10K | CPF0201D7K68C1_CPF0201D7K68C1 | CPF0201D7K68C1_0201 | 7.68k 0201 Thin Film Surface Mount Fixed Resistor +/-0.5% 0.031W CPF0201D7K68C1
R_TYPE_SEL | 2.2 | CPF0201D7K68C1_CPF0201D7K68C1 | CPF0201D7K68C1_0201 | 7.68k 0201 Thin Film Surface Mount Fixed Resistor +/-0.5% 0.031W CPF0201D7K68C1
SJ1 |  | ESP32_C6_LIBRARY_7_JUMPER_SJ | ESP32_C6_LIBRARY_7_JUMPER_SJ | SMD solder JUMPER |  |  |  |  |  |  |  |  |  |  |  |  |  |  |  |  |  |  |  | 3
SW_DN | 2025-10-22_07-23-44_LIBRARY_EVP-AKE31ASW_EVP-AKE31A_PAN | 2025-10-22_07-23-44_LIBRARY_EVP-AKE31ASW_EVP-AKE31A_PAN | 2025-10-22_07-23-44_LIBRARY_SW_EVP-AKE31A_PAN |  |  |  |  |  | Copyright (C) 2025 Ultra Librarian. All rights reserved. |  | P123437TR-ND | P123437CT-ND | P123437DKR-ND |  |  | Panasonic | EVP-AKE31A
SW_ENT | 2025-10-22_07-23-44_LIBRARY_EVP-AKE31ASW_EVP-AKE31A_PAN | 2025-10-22_07-23-44_LIBRARY_EVP-AKE31ASW_EVP-AKE31A_PAN | 2025-10-22_07-23-44_LIBRARY_SW_EVP-AKE31A_PAN |  |  |  |  |  | Copyright (C) 2025 Ultra Librarian. All rights reserved. |  | P123437TR-ND | P123437CT-ND | P123437DKR-ND |  |  | Panasonic | EVP-AKE31A
SW_UP | 2025-10-22_07-23-44_LIBRARY_EVP-AKE31ASW_EVP-AKE31A_PAN | 2025-10-22_07-23-44_LIBRARY_EVP-AKE31ASW_EVP-AKE31A_PAN | 2025-10-22_07-23-44_LIBRARY_SW_EVP-AKE31A_PAN |  |  |  |  |  | Copyright (C) 2025 Ultra Librarian. All rights reserved. |  | P123437TR-ND | P123437CT-ND | P123437DKR-ND |  |  | Panasonic | EVP-AKE31A
TP1 | HECTOR_WATCH_1_TPTP20R | HECTOR_WATCH_1_TPTP20R | HECTOR_WATCH_1_TP20R | Test pad |  |  |  |  |  |  |  |  |  |  |  |  |  |  |  |  |  |  |  | 2
TP2 | HECTOR_WATCH_1_TPTP20R | HECTOR_WATCH_1_TPTP20R | HECTOR_WATCH_1_TP20R | Test pad |  |  |  |  |  |  |  |  |  |  |  |  |  |  |  |  |  |  |  | 2
TP_3.3V | HECTOR_WATCH_1_TPTP20R | HECTOR_WATCH_1_TPTP20R | HECTOR_WATCH_1_TP20R | Test pad |  |  |  |  |  |  |  |  |  |  |  |  |  |  |  |  |  |  |  | 2
TP_3V3 | HECTOR_WATCH_1_TPTP20R | HECTOR_WATCH_1_TPTP20R | HECTOR_WATCH_1_TP20R | Test pad |  |  |  |  |  |  |  |  |  |  |  |  |  |  |  |  |  |  |  | 2
TP_GND | HECTOR_WATCH_1_TPTP20R | HECTOR_WATCH_1_TPTP20R | HECTOR_WATCH_1_TP20R | Test pad |  |  |  |  |  |  |  |  |  |  |  |  |  |  |  |  |  |  |  | 2
TP_ON | HECTOR_WATCH_1_TPTP20R | HECTOR_WATCH_1_TPTP20R | HECTOR_WATCH_1_TP20R | Test pad |  |  |  |  |  |  |  |  |  |  |  |  |  |  |  |  |  |  |  | 2
TP_OP | HECTOR_WATCH_1_TPTP20R | HECTOR_WATCH_1_TPTP20R | HECTOR_WATCH_1_TP20R | Test pad |  |  |  |  |  |  |  |  |  |  |  |  |  |  |  |  |  |  |  | 2
TP_RESET | HECTOR_WATCH_1_TPTP20R | HECTOR_WATCH_1_TPTP20R | HECTOR_WATCH_1_TP20R | Test pad |  |  |  |  |  |  |  |  |  |  |  |  |  |  |  |  |  |  |  | 2
TP_SCL | HECTOR_WATCH_1_TPTP20R | HECTOR_WATCH_1_TPTP20R | HECTOR_WATCH_1_TP20R | Test pad |  |  |  |  |  |  |  |  |  |  |  |  |  |  |  |  |  |  |  | 2
TP_SDA | HECTOR_WATCH_1_TPTP20R | HECTOR_WATCH_1_TPTP20R | HECTOR_WATCH_1_TP20R | Test pad |  |  |  |  |  |  |  |  |  |  |  |  |  |  |  |  |  |  |  | 2
TP_SWDCLK | HECTOR_WATCH_1_TPTP20R | HECTOR_WATCH_1_TPTP20R | HECTOR_WATCH_1_TP20R | Test pad |  |  |  |  |  |  |  |  |  |  |  |  |  |  |  |  |  |  |  | 2
TP_SWDIO | HECTOR_WATCH_1_TPTP20R | HECTOR_WATCH_1_TPTP20R | HECTOR_WATCH_1_TP20R | Test pad |  |  |  |  |  |  |  |  |  |  |  |  |  |  |  |  |  |  |  | 2
TP_SWO | HECTOR_WATCH_1_TPTP20R | HECTOR_WATCH_1_TPTP20R | HECTOR_WATCH_1_TP20R | Test pad |  |  |  |  |  |  |  |  |  |  |  |  |  |  |  |  |  |  |  | 2
TP_VREG | HECTOR_WATCH_1_TPTP20R | HECTOR_WATCH_1_TPTP20R | HECTOR_WATCH_1_TP20R | Test pad |  |  |  |  |  |  |  |  |  |  |  |  |  |  |  |  |  |  |  | 2
U$2 |  | NORDIC_NRF_3_CAPACITOR_0201_L | NORDIC_NRF_3_RESC0201_L | Generic chip capacitor
U1 | NORDIC_NRF_4_NRF52840_QF | NORDIC_NRF_4_NRF52840_QF | NORDIC_NRF_4_AQFN50P700X700X85_HS-74N | nRF52840
U3 | ESP32_C6_LIBRARY_MAX17048G+T10 | ESP32_C6_LIBRARY_MAX17048G+T10 | ESP32_C6_LIBRARY_SON50P200X200X80-9N | Check availability |  |  | In Stock | https://www.snapeda.com/parts/MAX17048G+T10/Analog+Devices/view-part/?ref=eda |  | 3µA 1-Cell/2-Cell Fuel Gauge with ModelGauge |  |  |  |  |  |  |  | Analog Devices |  |  |  | MAX17048G+T10 | TDFN-8 Maxim |  | None |  | https://www.snapeda.com/api/url_track_click_mouser/?unipart_id=329239&manufacturer=Analog Devices&part_name=MAX17048G+T10&search_term=None | https://www.snapeda.com/parts/MAX17048G+T10/Analog+Devices/view-part/?ref=snap
X1 | 32MHz | NORDIC_NRF_XTAL_32MHZ | NORDIC_NRF_BT-XTAL_2016_N
X2 | 32.768kHz | NORDIC_NRF_1_XTAL_32KHZ | NORDIC_NRF_1_XTAL_3215_N

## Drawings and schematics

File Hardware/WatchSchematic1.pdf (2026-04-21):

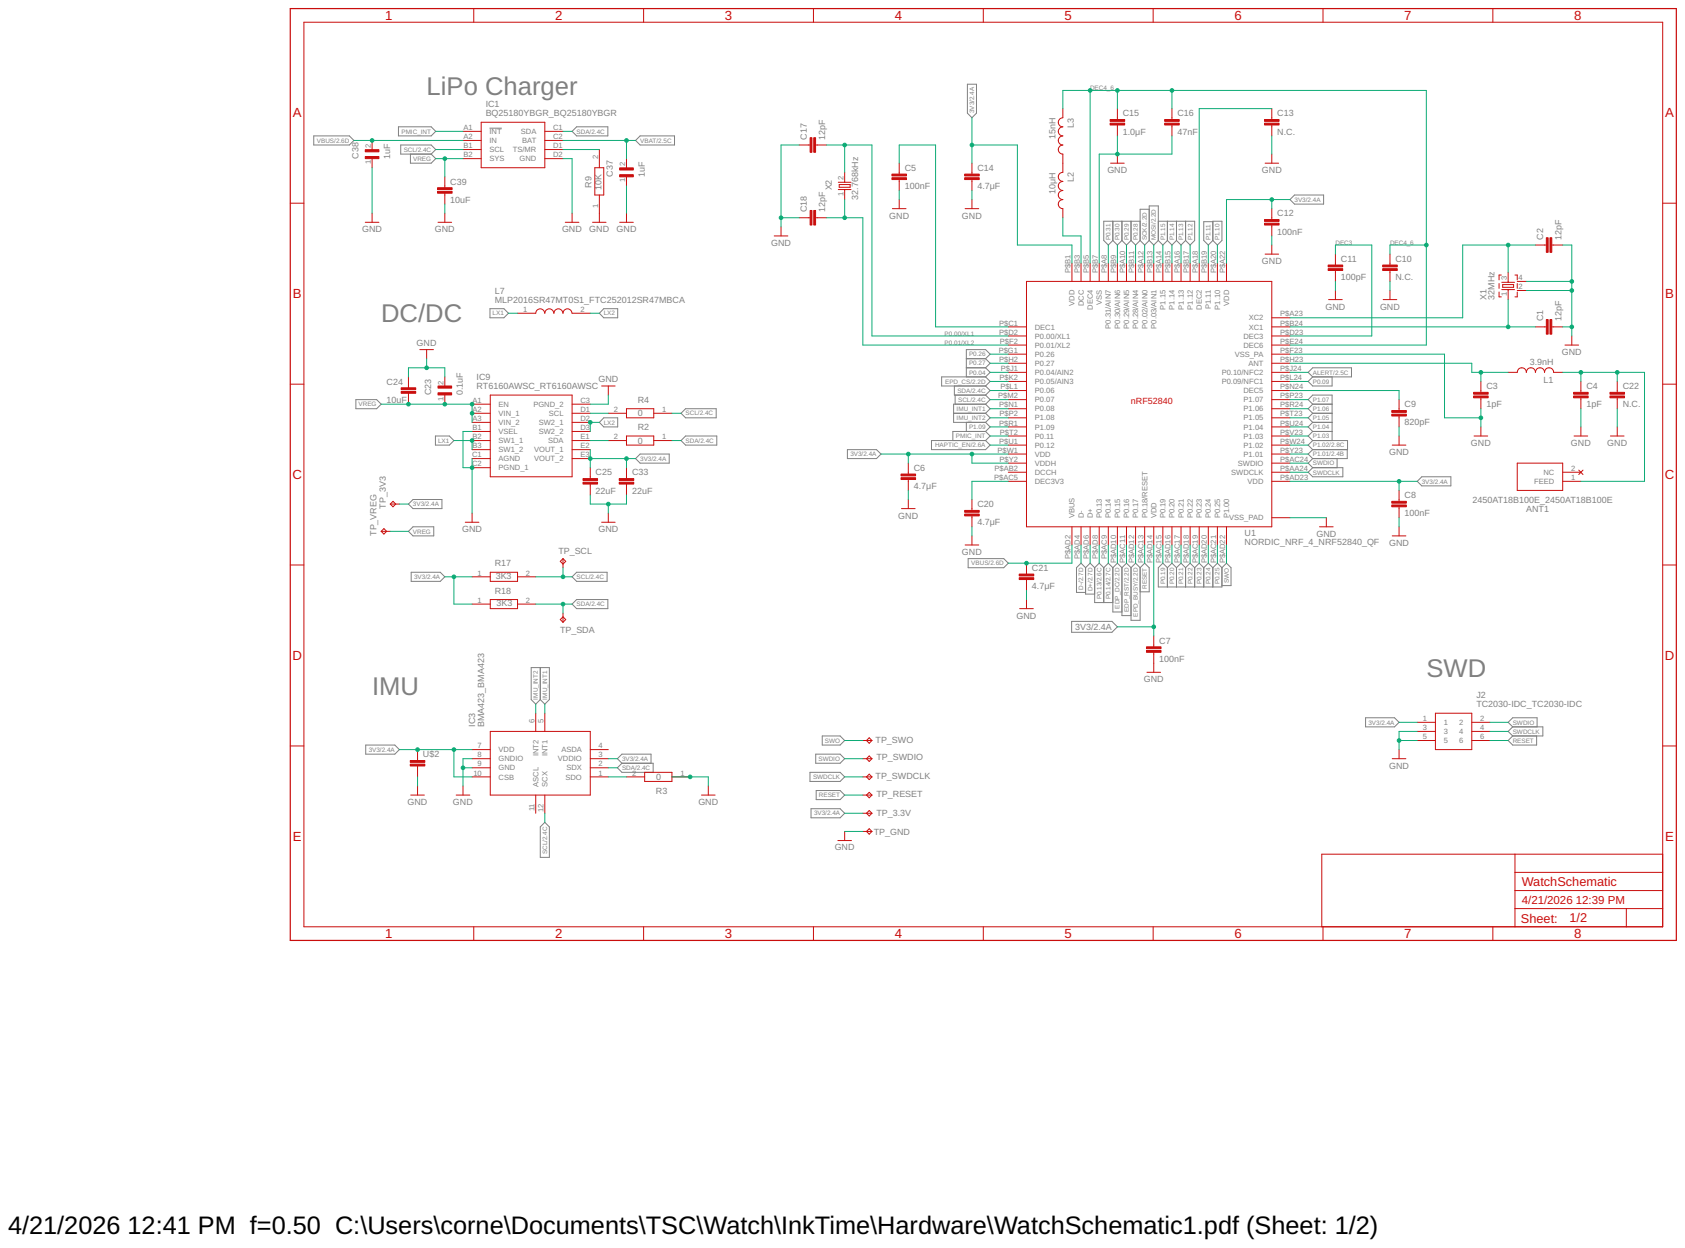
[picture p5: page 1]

4/21/2026 12:41 PM f=0.50 C:\Users\corne\Documents\TSC\Watch\InkTime\Hardware\WatchSchematic1.pdf (Sheet: 1/2)

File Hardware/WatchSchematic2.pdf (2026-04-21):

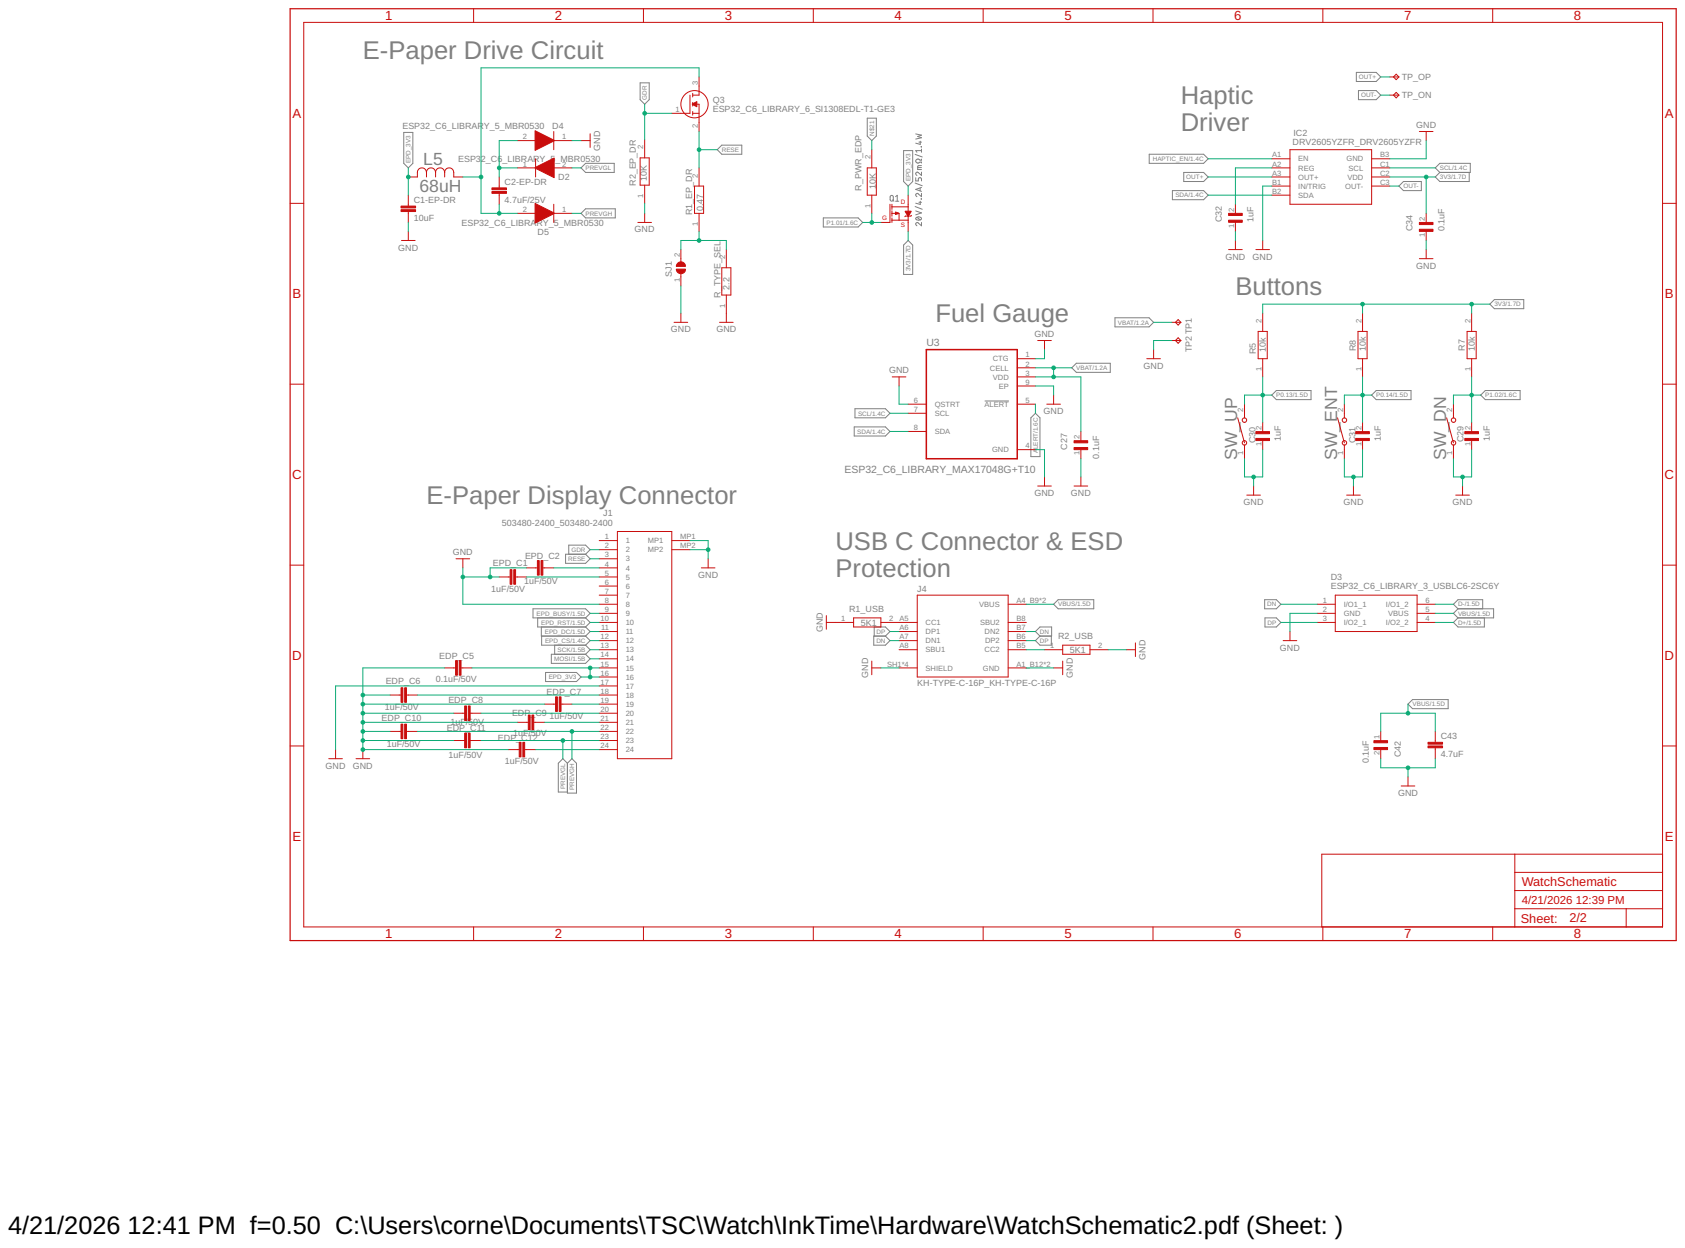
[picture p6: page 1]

19 20 | VBUS/1.5D

4/21/2026 12:41 PM f=0.50 C:\Users\corne\Documents\TSC\Watch\InkTime\Hardware\WatchSchematic2.pdf (Sheet: )

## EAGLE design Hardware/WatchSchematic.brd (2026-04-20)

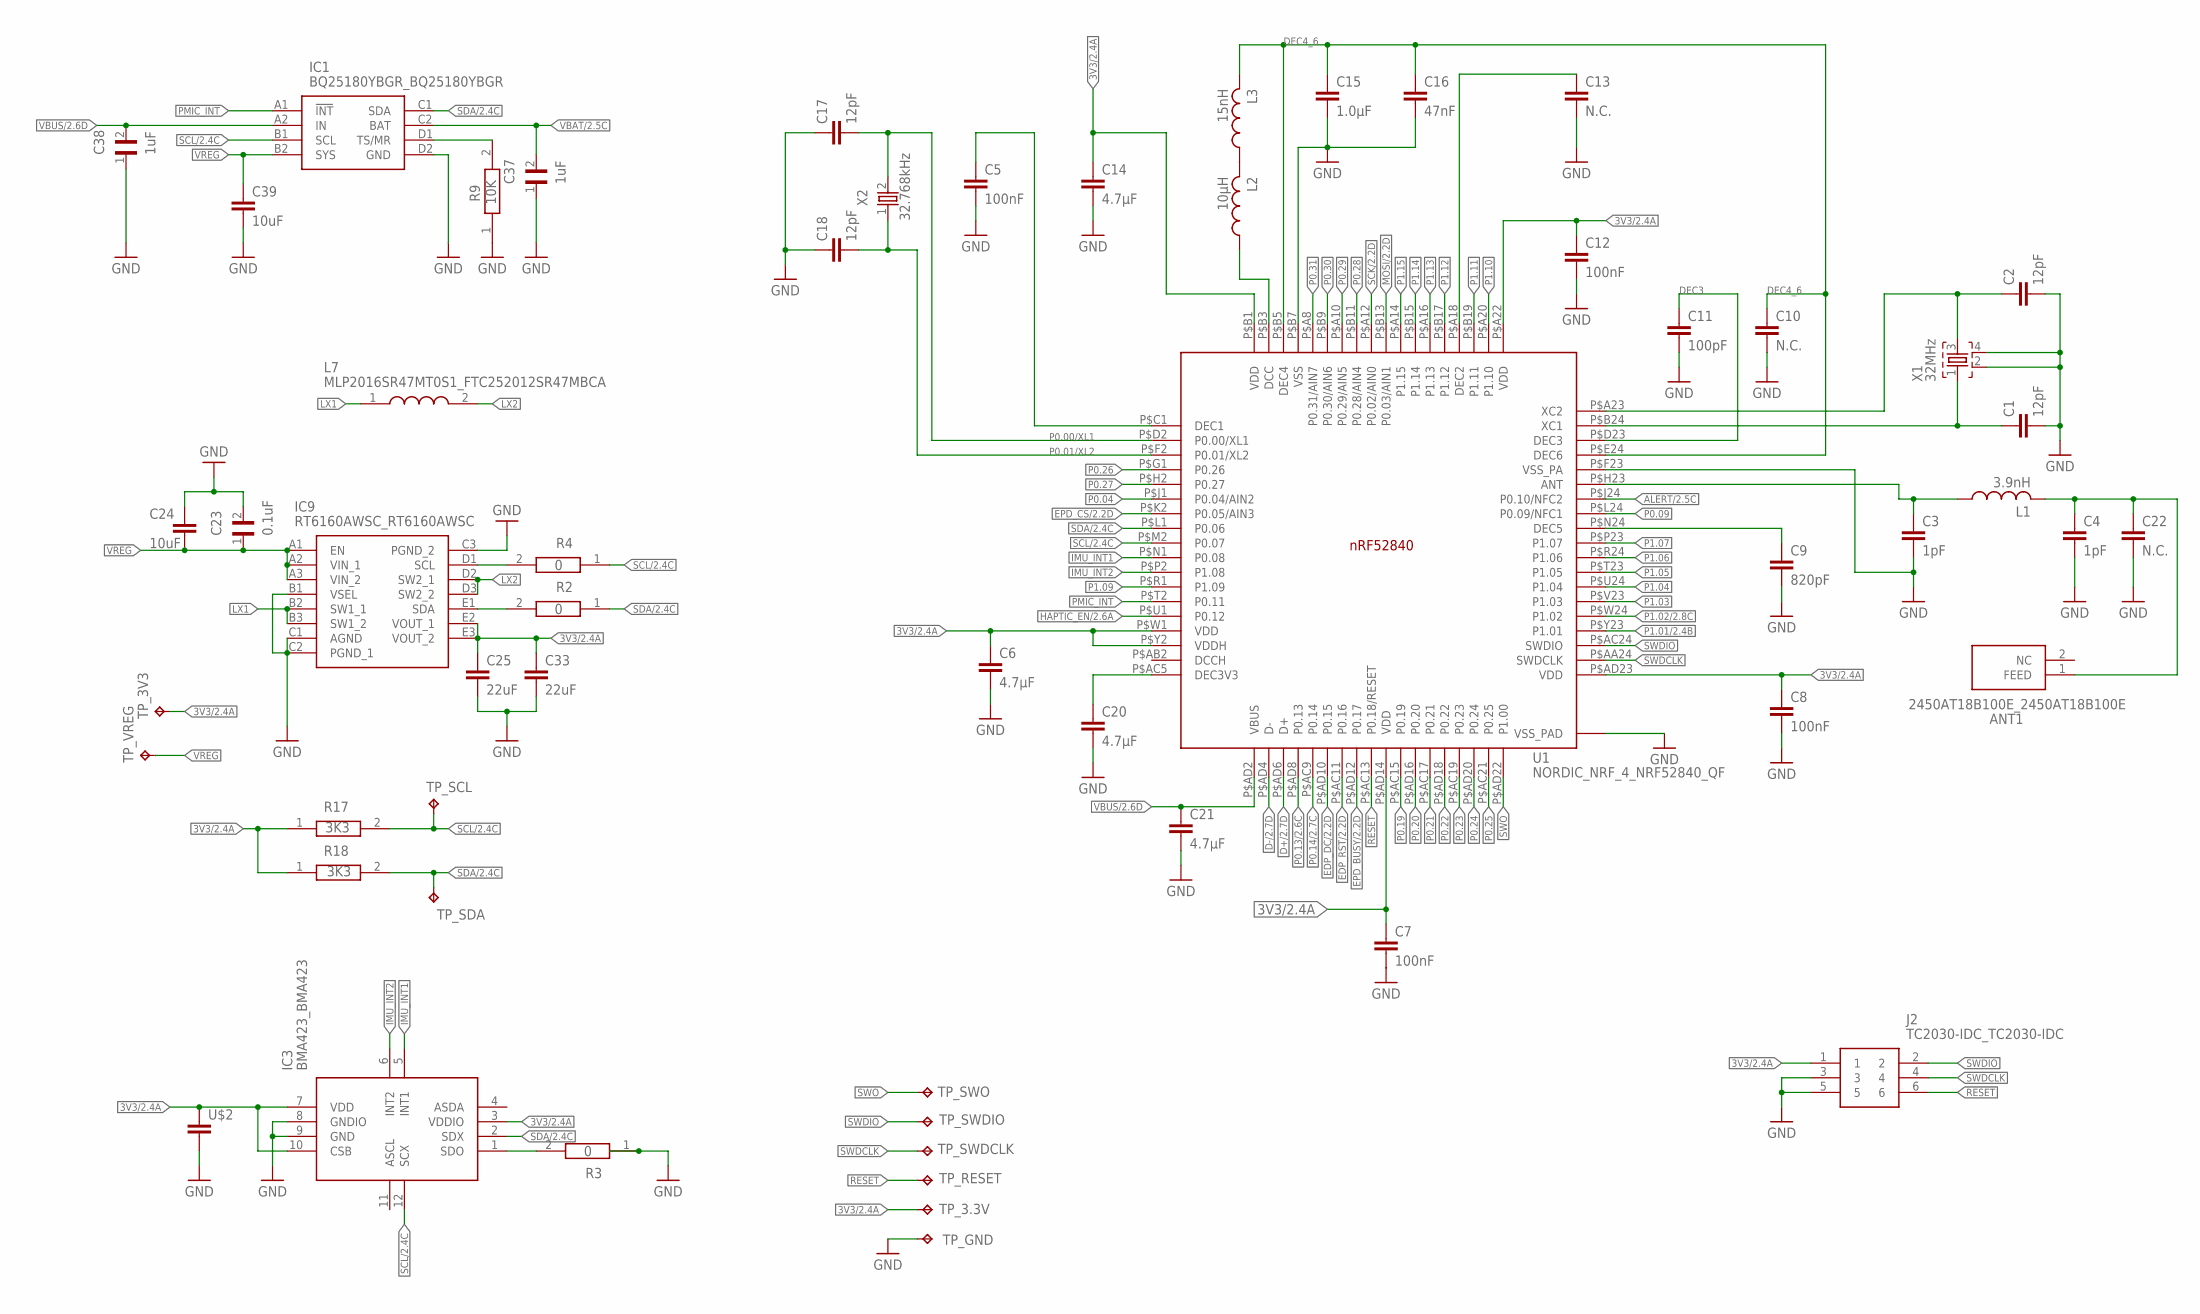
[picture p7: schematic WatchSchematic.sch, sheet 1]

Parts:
ANT1: 2450AT18B100E_2450AT18B100E; 2450AT18B100E_ANTC3216X140N
C1, C2, C17, C18: 12pF; NORDIC_NRF_3_RESC0201_L
C3, C4: 1pF; NORDIC_NRF_3_RESC0201_L
C5, C7, C8, C12: 100nF; NORDIC_NRF_3_RESC0201_L
C6, C14, C20, C21: 4.7μF; NORDIC_NRF_3_RESC0201_L
C9: 820pF; NORDIC_NRF_3_RESC0201_L
C10, C13, C22: N.C.; NORDIC_NRF_3_RESC0201_L
C11: 100pF; NORDIC_NRF_3_RESC0201_L
C15: 1.0μF; NORDIC_NRF_3_RESC0201_L
C16: 47nF; NORDIC_NRF_3_RESC0201_L
C23: 0.1uF; GRM011R60J152KE01L_1_0201
C24, C39: 10uF; NORDIC_NRF_3_RESC0201_L
C25, C33: 22uF; NORDIC_NRF_3_RESC0201_L
C37, C38: 1uF; GRM011R60J152KE01L_1_0201
IC1: BQ25180YBGR_BQ25180YBGR; BQ25180YBGR_BGA8C40P2X4_100X155X50
IC3: BMA423_BMA423
IC9: RT6160AWSC_RT6160AWSC; RT6160AWSC_BGA15C40P3X5_140X230X60
J2: TC2030-IDC_TC2030-IDC; TC2030-IDC_TC2030IDC
L1: 3.9nH; NORDIC_NRF_2_RESC0402_L
L2: 10μH; NORDIC_NRF_2_RESC0402_L
L3: 15nH; NORDIC_NRF_2_RESC0402_L
L7: MLP2016SR47MT0S1_FTC252012SR47MBCA; MLP2016SR47MT0S1_INDC2016X100N
R2, R3, R4: 0; CPF0201D7K68C1_0201
R9: 10K; CPF0201D7K68C1_0201
R17, R18: 3K3; CPF0201D7K68C1_0201
TP_3.3V, TP_3V3: HECTOR_WATCH_1_TPTP20R; HECTOR_WATCH_1_TP20R
TP_GND: HECTOR_WATCH_1_TPTP20R; HECTOR_WATCH_1_TP20R
TP_RESET: HECTOR_WATCH_1_TPTP20R; HECTOR_WATCH_1_TP20R
TP_SCL: HECTOR_WATCH_1_TPTP20R; HECTOR_WATCH_1_TP20R
TP_SDA: HECTOR_WATCH_1_TPTP20R; HECTOR_WATCH_1_TP20R
TP_SWDCLK: HECTOR_WATCH_1_TPTP20R; HECTOR_WATCH_1_TP20R
TP_SWDIO: HECTOR_WATCH_1_TPTP20R; HECTOR_WATCH_1_TP20R
TP_SWO: HECTOR_WATCH_1_TPTP20R; HECTOR_WATCH_1_TP20R
TP_VREG: HECTOR_WATCH_1_TPTP20R; HECTOR_WATCH_1_TP20R
U1: NORDIC_NRF_4_NRF52840_QF; NORDIC_NRF_4_AQFN50P700X700X85_HS-74N
U$2: NORDIC_NRF_3_CAPACITOR_0201_L; NORDIC_NRF_3_RESC0201_L
X1: 32MHz; NORDIC_NRF_BT-XTAL_2016_N
X2: 32.768kHz; NORDIC_NRF_1_XTAL_3215_N

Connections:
3V3/2.4A: C6.1, C7.1, C8.1, C12.1, C14.1, C25.1, C33.1, IC3.3 (VDDIO), IC3.7 (VDD), IC3.10 (CSB), IC9.E2 (VOUT_1), IC9.E3 (VOUT_2), J2.1, R17.1, R18.1, TP_3.3V.TP, TP_3V3.TP, U1.P$A22 (VDD), U1.P$AD14 (VDD), U1.P$AD23 (VDD), U1.P$B1 (VDD), U1.P$W1 (VDD), U1.P$Y2 (VDDH), U$2.1
ALERT/2.5C: U1.P$J24 (P0.10/NFC2)
D+/2.7D: U1.P$AD6 (D+)
D-/2.7D: U1.P$AD4 (D-)
DEC3: C11.1, U1.P$D23 (DEC3)
DEC4_6: C10.1, C15.1, C16.1, L3.2, U1.P$B5 (DEC4), U1.P$E24 (DEC6)
EDP_DC/2.2D: U1.P$AD10 (P0.15)
EDP_RST/2.2D: U1.P$AC11 (P0.16)
EPD_BUSY/2.2D: U1.P$AD12 (P0.17)
EPD_CS/2.2D: U1.P$K2 (P0.05/AIN3)
GND: C1.2, C2.2, C3.2, C4.2, C5.2, C6.2, C7.2, C8.2, C9.2, C10.2, C11.2, C12.2, C13.2, C14.2, C15.2, C16.2, C17.1, C18.1, C20.2, C21.2, C22.2, C23.2, C24.1, C25.2, C33.2, C37.1, C38.1, C39.2, IC1.D2 (GND), IC3.8 (GNDIO), IC3.9 (GND), IC9.B1 (VSEL), IC9.C1 (AGND), IC9.C2 (PGND_1), IC9.C3 (PGND_2), J2.3, J2.5, R3.1, R9.1, TP_GND.TP, U1.P$74 (VSS_PAD), U1.P$75 (VSS_PAD), U1.P$76 (VSS_PAD), U1.P$77 (VSS_PAD), U1.P$78 (VSS_PAD), U1.P$79 (VSS_PAD), U1.P$80 (VSS_PAD), U1.P$81 (VSS_PAD), U1.P$82 (VSS_PAD), U1.P$83 (VSS_PAD), U1.P$84 (VSS_PAD), U1.P$85 (VSS_PAD), U1.P$86 (VSS_PAD), U1.P$87 (VSS_PAD), U1.P$88 (VSS_PAD), U1.P$89 (VSS_PAD), U1.P$90 (VSS_PAD), U1.P$B7 (VSS), U1.P$F23 (VSS_PA), U$2.2, X1.2, X1.4; also elsewhere on the board
HAPTIC_EN/2.6A: U1.P$U1 (P0.12)
IMU_INT1: IC3.5 (INT1), U1.P$N1 (P0.08)
IMU_INT2: IC3.6 (INT2), U1.P$P2 (P1.08)
LX1: IC9.B2 (SW1_1), IC9.B3 (SW1_2), L7.1
LX2: IC9.D2 (SW2_1), IC9.D3 (SW2_2), L7.2
MOSI/2.2D: U1.P$B13 (P0.03/AIN1)
unnamed: IC9.E1 (SDA), R2.2
unnamed: IC1.D1 (TS/MR), R9.2
unnamed: C5.1, U1.P$C1 (DEC1)
unnamed: IC3.1 (SDO), R3.2
unnamed: L2.2, L3.1
unnamed: L2.1, U1.P$B3 (DCC)
unnamed: IC9.D1 (SCL), R4.2
unnamed: C13.1, U1.P$A18 (DEC2)
unnamed: C1.1, U1.P$B24 (XC1), X1.1
unnamed: C2.1, U1.P$A23 (XC2), X1.3
unnamed: C9.1, U1.P$N24 (DEC5)
unnamed: C3.1, L1.1, U1.P$H23 (ANT)
unnamed: ANT1.1 (FEED), C4.1, C22.1, L1.2
unnamed: C20.1, U1.P$AC5 (DEC3V3)
P0.00/XL1: C17.2, U1.P$D2 (P0.00/XL1), X2.2
P0.01/XL2: C18.2, U1.P$F2 (P0.01/XL2), X2.1
P0.04: U1.P$J1 (P0.04/AIN2)
P0.09: U1.P$L24 (P0.09/NFC1)
P0.13/2.6C: U1.P$AD8 (P0.13)
P0.14/2.7C: U1.P$AC9 (P0.14)
P0.19: U1.P$AC15 (P0.19)
P0.20: U1.P$AD16 (P0.20)
P0.21: U1.P$AC17 (P0.21)
P0.22: U1.P$AD18 (P0.22)
P0.23: U1.P$AC19 (P0.23)
P0.24: U1.P$AD20 (P0.24)
P0.25: U1.P$AC21 (P0.25)
P0.26: U1.P$G1 (P0.26)
P0.27: U1.P$H2 (P0.27)
P0.28: U1.P$B11 (P0.28/AIN4)
P0.29: U1.P$A10 (P0.29/AIN5)
P0.30: U1.P$B9 (P0.30/AIN6)
P0.31: U1.P$A8 (P0.31/AIN7)
P1.01/2.4B: U1.P$Y23 (P1.01)
P1.02/2.8C: U1.P$W24 (P1.02)
P1.03: U1.P$V23 (P1.03)
P1.04: U1.P$U24 (P1.04)
P1.05: U1.P$T23 (P1.05)
P1.06: U1.P$R24 (P1.06)
P1.07: U1.P$P23 (P1.07)
P1.09: U1.P$R1 (P1.09)
P1.10: U1.P$A20 (P1.10)
P1.11: U1.P$B19 (P1.11)
P1.12: U1.P$B17 (P1.12)
P1.13: U1.P$A16 (P1.13)
P1.14: U1.P$B15 (P1.14)
P1.15: U1.P$A14 (P1.15)
PMIC_INT: IC1.A1 (!INT), U1.P$T2 (P0.11)
RESET: J2.6, TP_RESET.TP, U1.P$AC13 (P0.18/RESET)
SCK/2.2D: U1.P$A12 (P0.02/AIN0)
SCL/2.4C: IC1.B1 (SCL), IC3.12 (SCX), R4.1, R17.2, TP_SCL.TP, U1.P$M2 (P0.07)
SDA/2.4C: IC1.C1 (SDA), IC3.2 (SDX), R2.1, R18.2, TP_SDA.TP, U1.P$L1 (P0.06)
SWDCLK: J2.4, TP_SWDCLK.TP, U1.P$AA24 (SWDCLK)
SWDIO: J2.2, TP_SWDIO.TP, U1.P$AC24 (SWDIO)
SWO: TP_SWO.TP, U1.P$AD22 (P1.00)
VBAT/2.5C: C37.2, IC1.C2 (BAT)
VBUS/2.6D: C21.1, C38.2, IC1.A2 (IN), U1.P$AD2 (VBUS)
VREG: C23.1, C24.2, C39.1, IC1.B2 (SYS), IC9.A1 (EN), IC9.A2 (VIN_1), IC9.A3 (VIN_2), TP_VREG.TP

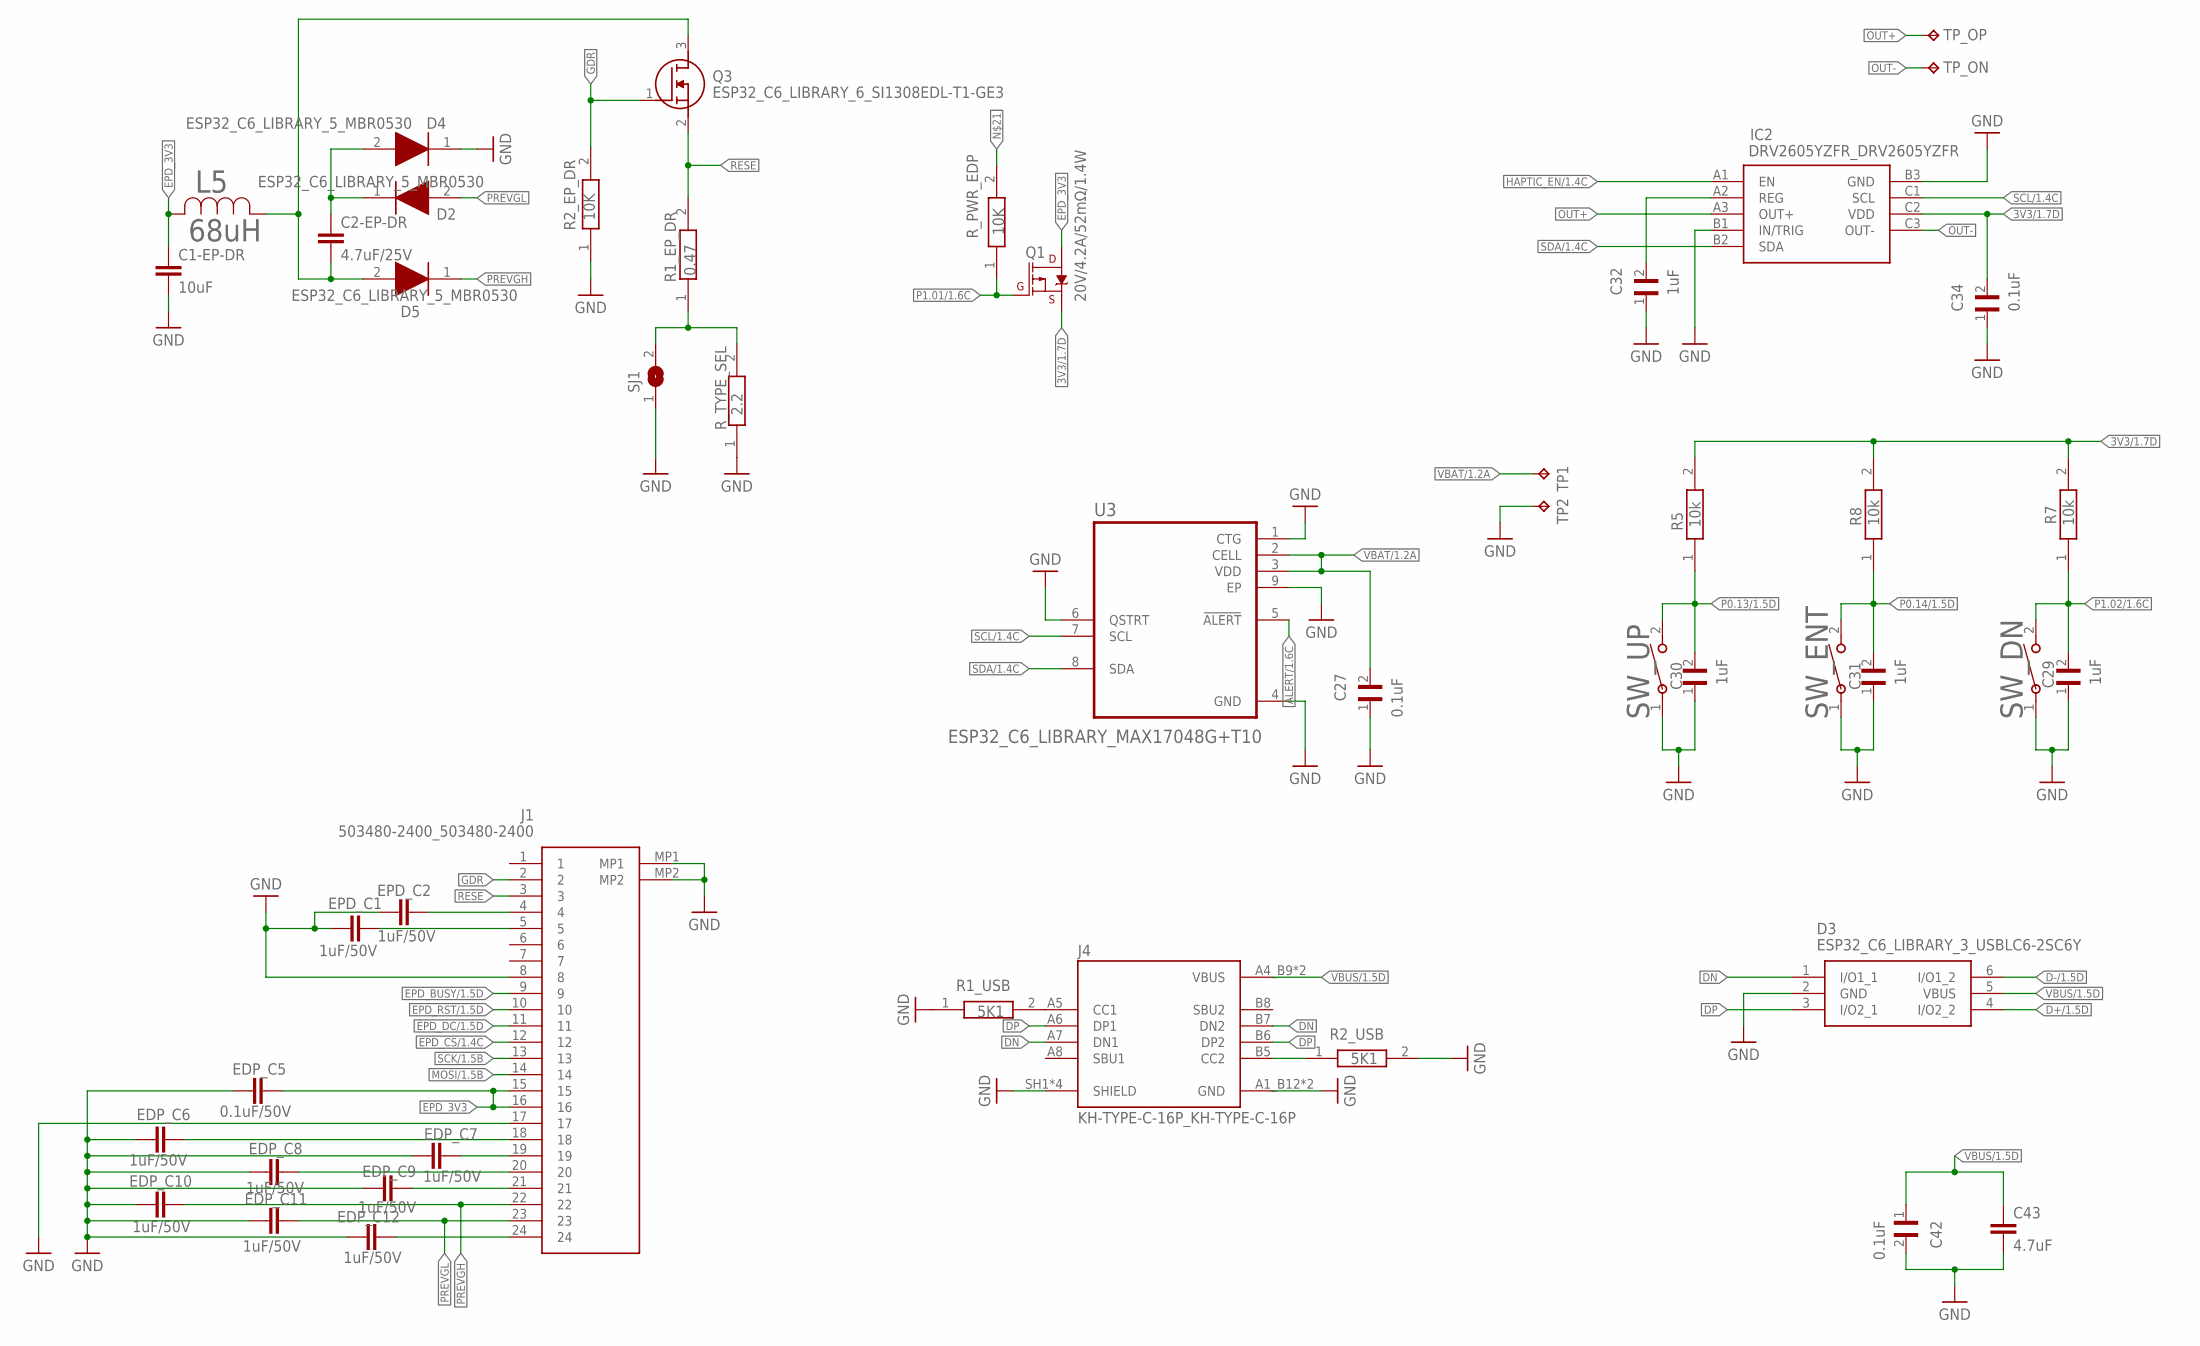
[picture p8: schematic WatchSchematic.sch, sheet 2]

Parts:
C1-EP-DR: 10uF; NORDIC_NRF_3_RESC0201_L
C2-EP-DR: 4.7uF/25V; NORDIC_NRF_3_RESC0201_L
C27, C34, C42: 0.1uF; GRM011R60J152KE01L_1_0201
C29, C30, C31, C32: 1uF; GRM011R60J152KE01L_1_0201
C43: 4.7uF; NORDIC_NRF_3_RESC0201_L
D2, D4, D5: ESP32_C6_LIBRARY_5_MBR0530; ESP32_C6_LIBRARY_5_SOD3716X135N
D3: ESP32_C6_LIBRARY_3_USBLC6-2SC6Y; ESP32_C6_LIBRARY_3_SOT95P280X145-6N
EDP_C5: 0.1uF/50V; NORDIC_NRF_3_RESC0201_L
EDP_C6, EDP_C7, EDP_C8, EDP_C9, EDP_C10, EDP_C11, EDP_C12: 1uF/50V; NORDIC_NRF_3_RESC0201_L
EPD_C1, EPD_C2: 1uF/50V; NORDIC_NRF_3_RESC0201_L
IC2: DRV2605YZFR_DRV2605YZFR; DRV2605YZFR_BGA9C50P3X3_144X144X62
J1: 503480-2400_503480-2400; 503480-2400_5034802400
J4: KH-TYPE-C-16P_KH-TYPE-C-16P; KH-TYPE-C-16P_KINGHELM_KH-TYPE-C-16P
L5: 68uH; ESP32_C6_LIBRARY_2_IND_4828-WE-TPC_WRE
Q1: 20V/4.2A/52mΩ/1.4W; ESP32_C6_LIBRARY_4_ESP32_C6_LIBRARY_4_ESP32_C6_LIBRARY_4_ES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
Q3: ESP32_C6_LIBRARY_6_SI1308EDL-T1-GE3; ESP32_C6_LIBRARY_6_SOT65P210X110-3N
R1_EP_DR: 0.47; CPF0201D7K68C1_0201
R1_USB, R2_USB: 5K1; CPF0201D7K68C1_0201
R2_EP_DR: 10K; CPF0201D7K68C1_0201
R5, R7, R8: 10k; CPF0201D7K68C1_0201
R_PWR_EDP: 10K; CPF0201D7K68C1_0201
R_TYPE_SEL: 2.2; CPF0201D7K68C1_0201
SJ1: ESP32_C6_LIBRARY_7_JUMPER_SJ
SW_DN: 2025-10-22_07-23-44_LIBRARY_EVP-AKE31ASW_EVP-AKE3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; 2025-10-22_07-23-44_LIBRARY_SW_EVP-AKE31A_PAN
SW_ENT: 2025-10-22_07-23-44_LIBRARY_EVP-AKE31ASW_EVP-AKE3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; 2025-10-22_07-23-44_LIBRARY_SW_EVP-AKE31A_PAN
SW_UP: 2025-10-22_07-23-44_LIBRARY_EVP-AKE31ASW_EVP-AKE3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; 2025-10-22_07-23-44_LIBRARY_SW_EVP-AKE31A_PAN
TP1, TP2: HECTOR_WATCH_1_TPTP20R; HECTOR_WATCH_1_TP20R
TP_ON: HECTOR_WATCH_1_TPTP20R; HECTOR_WATCH_1_TP20R
TP_OP: HECTOR_WATCH_1_TPTP20R; HECTOR_WATCH_1_TP20R
U3: ESP32_C6_LIBRARY_MAX17048G+T10; ESP32_C6_LIBRARY_SON50P200X200X80-9N

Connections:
3V3/1.7D: C34.2, IC2.C2 (VDD), Q1.2 (S), R5.2, R7.2, R8.2
ALERT/1.6C: U3.5 (!ALERT)
D+/1.5D: D3.4 (I/O2_2)
D-/1.5D: D3.6 (I/O1_2)
DN: D3.1 (I/O1_1), J4.A7 (DN1), J4.B7 (DN2)
DP: D3.3 (I/O2_1), J4.A6 (DP1), J4.B6 (DP2)
EPD_3V3: C1-EP-DR.1, EDP_C5.2, J1.15, J1.16, L5.2, Q1.3 (D)
EPD_BUSY/1.5D: J1.9
EPD_CS/1.4C: J1.12
EPD_DC/1.5D: J1.11
EPD_RST/1.5D: J1.10
GDR: J1.2, Q3.1 (G), R2_EP_DR.2
GND: C1-EP-DR.2, C27.1, C29.1, C30.1, C31.1, C32.1, C34.1, C42.2, C43.2, D3.2 (GND), D4.1 (K), EDP_C5.1, EDP_C6.1, EDP_C7.1, EDP_C8.1, EDP_C9.1, EDP_C10.1, EDP_C11.1, EDP_C12.1, EPD_C1.1, EPD_C2.1, IC2.B1 (IN/TRIG), IC2.B3 (GND), J1.8, J1.17, J1.MP1, J1.MP2, J4.A1_B12 (GND), J4.A12_B1 (GND), J4.SH1 (SHIELD), J4.SH2 (SHIELD), J4.SH3 (SHIELD), J4.SH4 (SHIELD), R1_USB.1, R2_EP_DR.1, R2_USB.2, R_TYPE_SEL.1, SJ1.1, SW_DN.1, SW_ENT.1, SW_UP.1, TP2.TP, U3.1 (CTG), U3.4 (GND), U3.6 (QSTRT), U3.9 (EP); also elsewhere on the board
HAPTIC_EN/1.4C: IC2.A1 (EN)
MOSI/1.5B: J1.14
unnamed: J4.A5 (CC1), R1_USB.2
unnamed: C2-EP-DR.2, D5.2 (A), L5.1, Q3.3 (D)
unnamed: C2-EP-DR.1, D2.1 (K), D4.2 (A)
unnamed: EPD_C2.2, J1.4
unnamed: EPD_C1.2, J1.5
unnamed: R1_EP_DR.1, R_TYPE_SEL.2, SJ1.2
unnamed: C32.2, IC2.A2 (REG)
unnamed: EDP_C7.2, J1.19
unnamed: EDP_C6.2, J1.18
unnamed: EDP_C8.2, J1.20
unnamed: EDP_C9.2, J1.21
unnamed: EDP_C12.2, J1.24
unnamed: J4.B5 (CC2), R2_USB.1
OUT+: IC2.A3 (OUT+), TP_OP.TP
OUT-: IC2.C3 (OUT-), TP_ON.TP
P0.13/1.5D: C30.2, R5.1, SW_UP.2
P0.14/1.5D: C31.2, R8.1, SW_ENT.2
P1.01/1.6C: Q1.1 (G), R_PWR_EDP.1
P1.02/1.6C: C29.2, R7.1, SW_DN.2
PREVGH: D5.1 (K), EDP_C10.2, J1.22
PREVGL: D2.2 (A), EDP_C11.2, J1.23
RESE: J1.3, Q3.2 (S), R1_EP_DR.2
SCK/1.5B: J1.13
SCL/1.4C: IC2.C1 (SCL), U3.7 (SCL)
SDA/1.4C: IC2.B2 (SDA), U3.8 (SDA)
VBAT/1.2A: C27.2, TP1.TP, U3.2 (CELL), U3.3 (VDD)
VBUS/1.5D: C42.1, C43.1, D3.5 (VBUS), J4.A4_B9 (VBUS), J4.A9_B4 (VBUS)

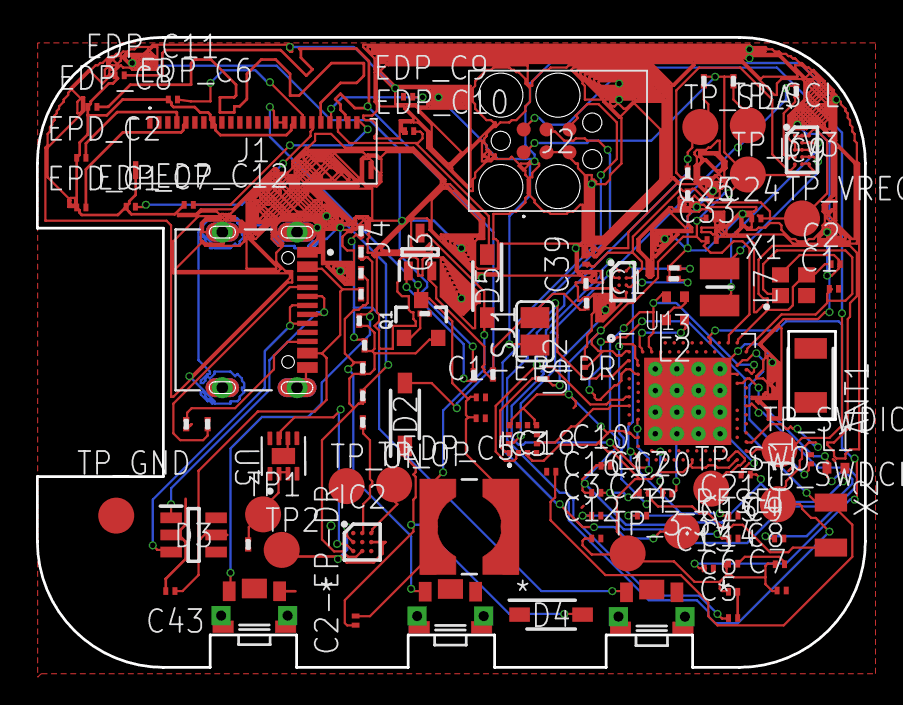
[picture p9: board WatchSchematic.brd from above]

Board: 2 copper layers, 46.0 x 35.0 mm, 105 parts (0 on the bottom side), 65 nets.

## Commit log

2026-04-08 + schematic files EVT
    [WatchSchematic.sch]
2026-04-09 + PCB layout EVT
    [WatchSchematic.brd]
2026-04-20 all done
    [WatchSchematic.brd, WatchSchematic.sch, bom.csv]
2026-04-21 solved issues
    [WatchSchematic.sch]

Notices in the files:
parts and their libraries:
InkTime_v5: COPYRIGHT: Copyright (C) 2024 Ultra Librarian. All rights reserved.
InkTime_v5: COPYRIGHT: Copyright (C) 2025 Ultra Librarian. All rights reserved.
